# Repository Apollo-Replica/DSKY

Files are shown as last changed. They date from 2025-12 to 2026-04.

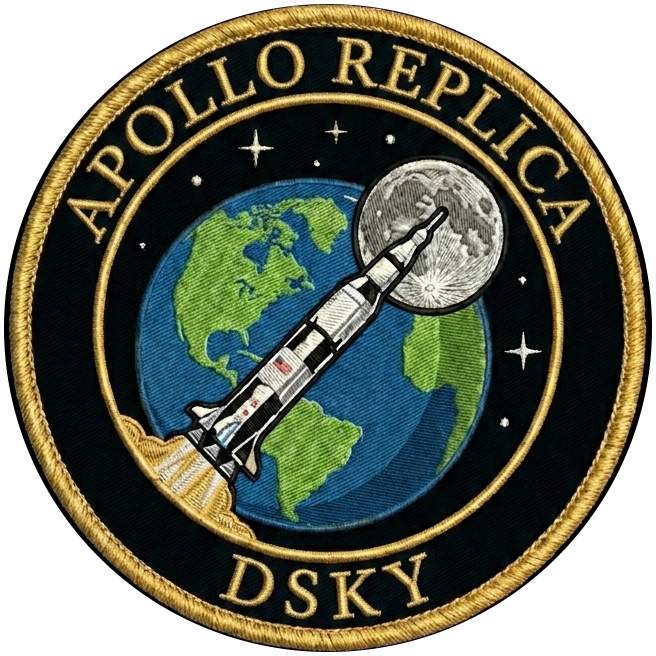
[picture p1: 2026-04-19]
Programs/orangepi-utilities/patch.png

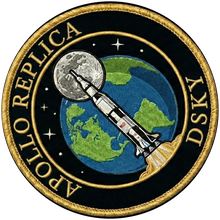
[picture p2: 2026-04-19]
Programs/orangepi-utilities/watermark.png

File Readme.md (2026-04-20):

# DSKY Replica
> This project is still a work-in-progress 

This projects aims to create an affordable and easy to manufacture, yet as realistic as possible replica of the DSKY used in the Apollo program to interface with the Apollo Guidance Computer (AGC).

## Quick start

**Do you want a DSKY but can't build one? Buy one [here](https://shop.ortizma.com)**

**Need Help? Join our Discord [here](https://discord.gg/CHZaYj5UNu)**

**Do you just want to have a DSKY display in your web browser?**
  - Make sure you have NodeJS > 18
  - Run start.bat and answer the prompts

**Do you want to build the whole DSKY replica?**
  - Print the .3mf/.stl meshes found in the '3D Models' folder.
    - The recommended display is the **960x544 AMOLED MIPI display**, connected to the Orange Pi via HDMI through an adapter board.
    - A legacy 40-Pin 5" 800x480 LCD variant also exists but is no longer recommended; new builds should use the AMOLED.
  - Order the PCB:
    - The board is designed to be ordered fully assembled from JLCPCB. The fabrication files (gerbers, BOM, pick-and-place positions) are in the ``Boards/Single_board/production`` folder.
  - Calibrate and flash the firmware:
    - Install PlatformIO into VSCode
    - Open this repository's root folder in VSCode — PlatformIO will pick up ``platformio.ini`` at the root
    - Each ATmega328P has a slightly different internal oscillator. You must first determine your chip's optimal OSCCAL value:
      1. Flash the ``bare_calibration`` environment to run the OSCCAL sweep
      2. Use ``firmware/tools/osccal_reader.py`` to read the sweep results and find the best value
      3. Set the ``-DOSC_CAL=0xNN`` flag in ``platformio.ini`` with your value
      4. Flash the ``bare`` environment with your calibrated firmware
  - Set up the Orange Pi:
    - See the [Orange Pi setup guide](Documentation/orangepi-setup.md).
    - Pre-built .img files have been shared around the community, but they are not recommended as they may be out of date.
  - Make sure you have NodeJS > 18
  - Run start.bat on your PC to launch the web display

## Repository contents:
* **Documentation**: Useful information to better understand how the different pieces of the puzzle talk to each other
* **2D Models**: SVG files for alarm labels and backlights.
* **3D Models**:
  * **0.4 Nozzle:** All printable meshes (enclosure, display housing, keyboard plate, mounts, etc.) designed for a standard 0.4mm nozzle.
  * **Keys (0.2 Nozzle + AMS).3mf:** Multi-color key models for a 0.2mm nozzle with AMS.
* **Firmware:** PlatformIO project containing the firmware for the bare ATmega328P on the PCB. Includes OSCCAL calibration tooling.
* **Programs:**
  * **next-dsky**: Full-stack Next.js application that serves as the main DSKY UI and backend. Handles serial communication with the PCB, WebSocket connections to AGC simulators, display rendering, and configuration.    * Requirements: NodeJS >18
    * Running: ``npm install`` then ``npm start`` (or use ``start.bat`` from the repo root)
  * **DSKY-Bridge**: Submodule ([nhadrian/DSKY-Bridge](https://github.com/nhadrian/DSKY-Bridge)) — bridge utility for the DSKY.
  * **nassp-cloud**: Node.js service that monitors NASSP (orbiter simulator) telemetry via WebSocket and manages automatic restarts.
  * **click-generator**: Python program that procedurally generates relay clicking audio sequences to emulate the DSKY's relay boxes.
* **Boards**
  * **Single_board**: Unified KiCad PCB project containing the keyboard matrix, alarm lights, serial interface, and backlight driver. The ``production`` folder contains ready-to-order JLCPCB fabrication files.

## License

This project is licensed under [Creative Commons Attribution-NonCommercial-ShareAlike 4.0 International (CC BY-NC-SA 4.0)](LICENSE).

You are free to build one for yourself, modify the design, and share your changes — as long as you **credit the original**, **do not use it commercially**, and **release your derivatives under the same license**. Commercial sale of this device or its derivatives is not permitted without prior written consent from the copyright holder.

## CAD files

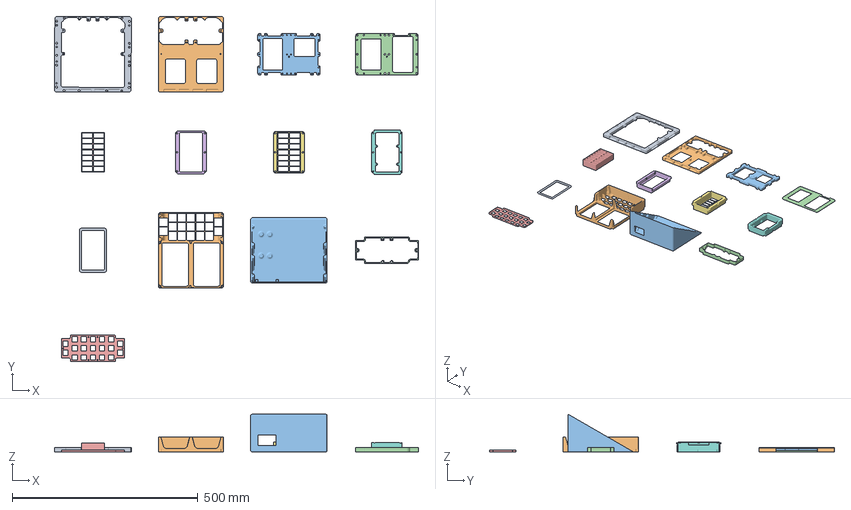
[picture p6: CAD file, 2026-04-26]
3D Models/0.4 Nozzle.3mf
980.6 x 929.7 x 101.6 mm
Mount Bottom
Mount Top
Gasket Bottom
Gasket Top.stl
Alarm Splitter.stl
Alarm Housing Top.stl
Alarm Housing Bottom.stl
Display Housing (OLED).stl
Frame (LCD).stl
Cover (LCD).stl
Compact Enclosure
Keyboard Holder
Keyboard Plate

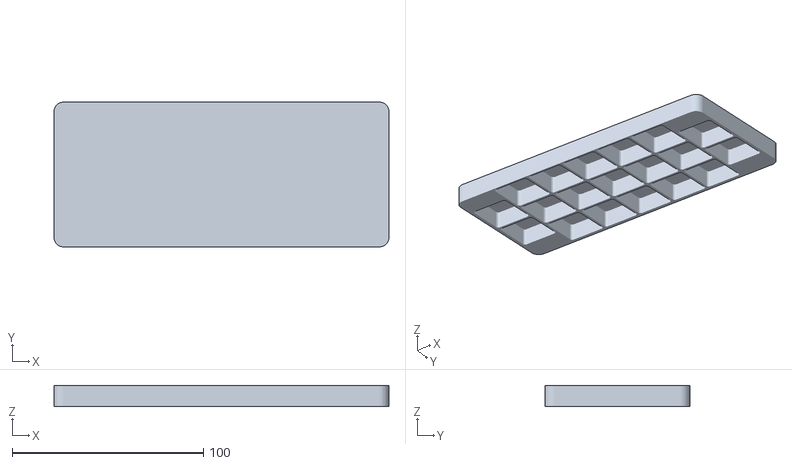
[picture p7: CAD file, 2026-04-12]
3D Models/(TOOL) Key Shipping Holder.stl
175.3 x 75.8 x 11.0

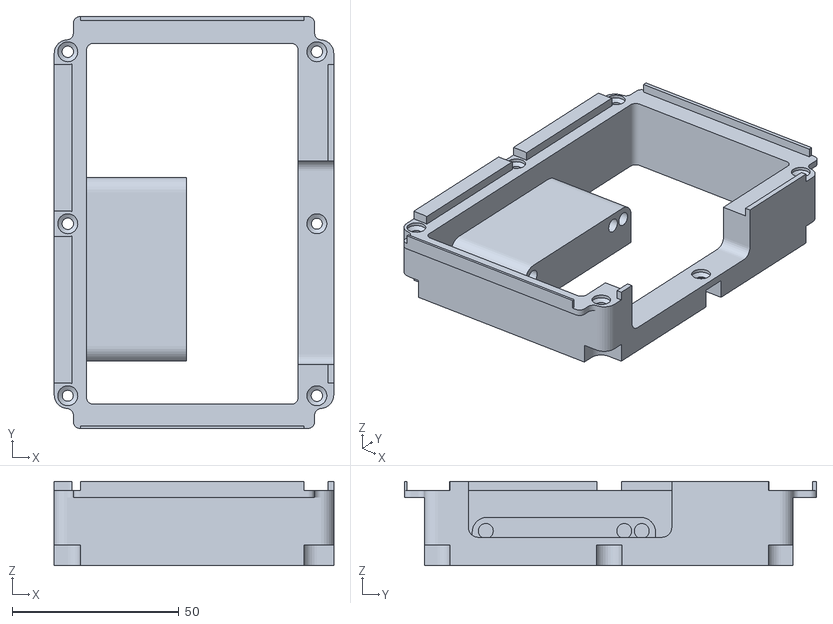
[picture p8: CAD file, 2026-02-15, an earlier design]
3D Models/(OLD) Display Housing (LCD).stl
83.8 x 123.5 x 25.3

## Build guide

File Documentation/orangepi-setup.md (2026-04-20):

# Orange Pi Zero 2W Setup Guide

This guide walks you through setting up an Orange Pi Zero 2W from scratch to run the DSKY software. This is the recommended approach over using pre-built .img files, which may be out of date.

## Base OS

Flash the official **Orange Pi Zero 2W** image (Ubuntu Jammy, arm64) to your SD card using your preferred tool (e.g. balenaEtcher, dd).

Default credentials are typically `orangepi` / `orangepi`.

## Initial setup

After first boot, connect via SSH or a monitor and keyboard.

```bash
# Set hostname
sudo hostnamectl set-hostname dsky

# Update the system
sudo apt update && sudo apt upgrade -y
```

### Create a swap file

The Orange Pi Zero 2W has limited RAM. A swap file helps prevent out-of-memory issues during `npm install` and builds.

```bash
sudo fallocate -l 1G /swapfile
sudo chmod 600 /swapfile
sudo mkswap /swapfile
sudo swapon /swapfile

# Make it permanent
echo '/swapfile swap swap sw 0 0' | sudo tee -a /etc/fstab
```

## Install dependencies

```bash
sudo apt install -y git x11vnc
```

### VirtualAGC (optional)

If you want to run the AGC simulator locally on the Orange Pi:

```bash
sudo apt-get install -y wx2.8-headers libwxgtk2.8-0 libsdl1.2debian libncurses5
```

Build VirtualAGC from source or use a pre-built release. The binaries should end up in `~/VirtualAGC/bin/` (notably `yaAGC`).

## Clone the DSKY repository

```bash
cd ~
git clone https://github.com/Apollo-Replica/DSKY.git
cd DSKY/Programs/next-dsky
npm install
npm run build
```

## Configure appliance-mode boot

Appliance mode boots the Orange Pi straight to the DSKY UI — no desktop, no login prompt, no visible Linux. A helper script does all the setup:

```bash
cd ~/DSKY
bash Programs/orangepi-utilities/setup-appliance-mode.sh
sudo reboot
```

What the script does:

- Installs `openbox`, `feh`, and `unclutter` (minimal WM, splash loader, cursor hider).
- Disables `apt-daily.timer` / `apt-daily-upgrade.timer` and removes `update-manager`/`update-notifier` so auto-updates don't fight the appliance.
- Sets silent kernel boot args in `/boot/orangepiEnv.txt` (`quiet splash loglevel=0`, hides console cursor and blanking).
- Registers a custom `dsky` X session and configures LightDM to auto-login the `orangepi` user into it.
- Creates `~/.xsession`, which launches `openbox` and runs `~/DSKY/orangepi.sh`.
- Silences the `getty@tty1` login banner.
- Swaps the Plymouth boot watermark to the DSKY mission patch.

After reboot: power on → splash image (or black screen) → DSKY UI.

The splash image lives at `~/DSKY/Programs/orangepi-utilities/splash.png`. Use portrait orientation matching your display (e.g. 544×960). If the file is missing the screen stays black until the UI is ready.

## Display rotation

The DSKY display is mounted in portrait orientation, so the HDMI output needs to be rotated 90° counterclockwise. `orangepi.sh` applies an xrandr transform automatically at startup.

The default transform is `0,-1,544,1,0,0,0,0,1`, where `544` is the height of the recommended 960×544 AMOLED display. Override via environment variables in `~/.xsession` (created by the appliance-mode script) only if your display differs:

```bash
#!/bin/bash
export DSKY_XRANDR_OUTPUT=HDMI-1                    # default: HDMI-1
export DSKY_XRANDR_TRANSFORM=0,-1,544,1,0,0,0,0,1   # match your display height
export DSKY_DISPLAY=amoled544                       # or lcd480 for the legacy 800×480 panel
openbox &
~/DSKY/orangepi.sh
```

> For the legacy 800×480 LCD: use `480` in place of `544` in the transform and set `DSKY_DISPLAY=lcd480`. Exporting `DSKY_DISPLAY` in `~/.xsession` is preferred over editing `Programs/next-dsky/.env` — `.xsession` env vars propagate through `orangepi.sh` into `next-dsky` at runtime.

## VNC access (optional)

To remotely view and control the Orange Pi's display:

```bash
# Set a VNC password
x11vnc -storepasswd

# Create a systemd service (more reliable than autostart desktop entries)
sudo tee /etc/systemd/system/x11vnc.service << 'EOF'
[Unit]
Description=x11vnc VNC server
After=display-manager.service

[Service]
Type=simple
ExecStart=/usr/bin/x11vnc -forever -usepw -display :0 -auth guess
User=orangepi
Restart=on-failure
RestartSec=3

[Install]
WantedBy=graphical.target
EOF

sudo systemctl daemon-reload
sudo systemctl enable x11vnc
sudo systemctl start x11vnc
```

## WiFi Connect (optional)

[wifi-connect](https://github.com/balena-os/wifi-connect) provides a captive portal for configuring WiFi on a headless device. The DSKY's configuration UI can trigger it.

```bash
# Install build dependencies
sudo apt install -y build-essential pkg-config libnm-dev libdbus-1-dev network-manager curl

# Install Rust
curl https://sh.rustup.rs -sSf | sh
source "$HOME/.cargo/env"

# Clone and build
git clone https://github.com/balena-os/wifi-connect.git ~/wifi-connect
cd ~/wifi-connect
cargo build --release

# Install the binary
sudo cp target/release/wifi-connect /usr/local/sbin/wifi-connect
```

The `orangepi.sh` launcher script already passes `--wifi-connect` to `next-dsky` when needed.

## Notes

- The Orange Pi connects to the PCB via USB serial (`/dev/ttyUSB0`).
- The `orangepi.sh` script handles display rotation, splash, starting `next-dsky` with the correct serial port, opening Chromium fullscreen, and restarting on crash.
- `unclutter` is launched by `orangepi.sh` to hide the mouse cursor immediately.
- The fstab uses `noatime,commit=600` to reduce SD card writes.
- To revert appliance mode: remove `~/.xsession`, `/etc/lightdm/lightdm.conf.d/50-appliance.conf`, `/usr/share/xsessions/dsky.desktop`, and `/etc/systemd/system/getty@tty1.service.d/override.conf`, then reboot.

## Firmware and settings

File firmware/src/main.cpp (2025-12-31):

#include <Arduino.h>
#include "alarms.h"
#include "keyboard.h"
#include "osc_calibration.h"

using namespace std;

const uint8_t PACKET_SIZE = 16;
constexpr uint32_t SERIAL_BAUD = 9600;
uint8_t dskyState[PACKET_SIZE];
uint8_t memoryLocation = 0;
uint8_t verbPresses = 0; // RGB Mode
uint8_t lightMode = 0;

void setup() {
#if defined(OSC_CAL_SWEEP)
  runOscCalibrationSweep();
  while (true) {}
#endif

  // Initialize state as only the RESTART alarm at low brightness.
  // This improves the chances that the OrangePi will boot successfully
  // while indicating correct Atmega power up.
  for(uint8_t i = 0; i<PACKET_SIZE;i++) dskyState[i] = 0x00;
  dskyState[12] = 0x04;
  dskyState[14] = 20;

  applyOscCalFromBuildFlag();
  Serial.begin(SERIAL_BAUD);
  initAlarms();
}

bool proPressed = false;
void loop() {
  // Serial input
  if(Serial.available() > 0){
    uint8_t receivedByte = Serial.read(); // Read the incoming byte

    if (receivedByte == 0xFF) { // Check if received byte is 0xFF
      memoryLocation = 0; // Reset the array index
    } else {
      dskyState[memoryLocation] = receivedByte; // Store the byte in the array
      memoryLocation = (memoryLocation + 1) % PACKET_SIZE; // Increment array index and wrap around if necessary
    }
  }

  // Keyboard input
  char pressedKey = getKey();
  if(pressedKey){
    Serial.println(pressedKey);
    if(pressedKey == 'P') proPressed = true;
    if(pressedKey != 'V') verbPresses = 0;
    if(pressedKey == 'V') verbPresses++;
  }
  if(getState() == RELEASED && proPressed){
    proPressed = false;
    Serial.println("O");
  }

  // Lighting
  if(verbPresses == 3){
    lightMode = (lightMode + 1) % 3;
    verbPresses = 0;
  }
  if(pressedKey == '+' && lightMode != 0){
    dskyState[14] = min(dskyState[14] + 20, 127);
    dskyState[15] = dskyState[14];
  }
  if(pressedKey == '-' && lightMode != 0){
    dskyState[14] = max(dskyState[14] - 20, 0);
    dskyState[15] = dskyState[14];
  }

  if (lightMode == 0) {
    // Display dsky state using neopixels
    updateAlarms(dskyState);
  }else if(lightMode == 1){
    // Display colorwheel effect
    colorWheel(dskyState);
  }else if(lightMode == 2){
    // Display colorwheel effect
    christmasEffect();
  }
}

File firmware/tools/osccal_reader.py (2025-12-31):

#!/usr/bin/env python3
"""
OSCCAL sweep reader for the calibration firmware.

The firmware emits bursts shaped like:
  0xA5 <cal_byte> 64 * 0x55 0x5A

This script listens on a serial port, parses bursts, scores them by how many
0x55 bytes were received correctly, and prints the best OSCCAL observed.

Usage:
  python osccal_reader.py --port COM3 --baud 115200 --bursts 40

Notes:
- Install dependency: pip install pyserial
- Match baud to the calibration firmware (default 115200).
- If your firmware uses a different burst length or markers, adjust constants
  below or override with CLI flags.
"""
from __future__ import annotations

import argparse
import collections
import sys
import time
from typing import Dict, List, Optional, Tuple

try:
    import serial  # type: ignore
    from serial.tools import list_ports  # type: ignore
except ImportError:
    print("pyserial is required. Install with: pip install pyserial", file=sys.stderr)
    sys.exit(1)


DEFAULT_BURST_LEN = 64
HEADER = 0xA5
FOOTER = 0x5A
PATTERN_BYTE = 0x55


Frame = Tuple[int, bytes]
Score = Tuple[int, int]  # (total correct, longest run)


def longest_run_of(byte_val: int, data: bytes) -> int:
    best = cur = 0
    for b in data:
        if b == byte_val:
            cur += 1
            if cur > best:
                best = cur
        else:
            cur = 0
    return best


def score_payload(payload: bytes) -> Score:
    correct = sum(1 for b in payload if b == PATTERN_BYTE)
    run = longest_run_of(PATTERN_BYTE, payload)
    return correct, run


def extract_frames(buf: bytearray, burst_len: int) -> Tuple[List[Frame], bytearray]:
    frames: List[Frame] = []
    i = 0
    min_frame = 2 + burst_len + 1  # header + cal + payload + footer
    while i <= len(buf) - min_frame:
        if buf[i] != HEADER:
            i += 1
            continue

        if i + min_frame > len(buf):
            break  # not enough data yet

        cal = buf[i + 1]
        payload = bytes(buf[i + 2 : i + 2 + burst_len])
        footer = buf[i + 2 + burst_len]
        if footer == FOOTER:
            frames.append((cal, payload))
            i += min_frame
        else:
            # Bad footer; discard this header and continue scanning
            i += 1

    # Trim processed bytes
    return frames, buf[i:]


def pick_best(scores: Dict[int, List[Score]]) -> Tuple[int, Score]:
    best_cal = None
    best_score: Score = (-1, -1)
    for cal, cal_scores in scores.items():
        cal_best = max(cal_scores)
        if cal_best > best_score:
            best_score = cal_best
            best_cal = cal
    if best_cal is None:
        raise RuntimeError("No valid frames decoded.")
    return best_cal, best_score


def summarize(scores: Dict[int, List[Score]], burst_len: int) -> Dict[int, Dict[str, float]]:
    summary: Dict[int, Dict[str, float]] = {}
    for cal, cal_scores in scores.items():
        corrects = [s[0] for s in cal_scores]
        runs = [s[1] for s in cal_scores]
        frames = len(cal_scores)
        summary[cal] = {
            "frames": frames,
            "avg_correct": sum(corrects) / frames,
            "min_correct": min(corrects),
            "max_correct": max(corrects),
            "avg_run": sum(runs) / frames,
            "max_run": max(runs),
            "perfect_frames": sum(1 for c in corrects if c == burst_len),
        }
    return summary


def best_perfect_span(scores: Dict[int, List[Score]], burst_len: int) -> Optional[Tuple[int, int, int]]:
    # Find the longest contiguous span of CAL values that had at least one perfect frame.
    perfect_cals = sorted(cal for cal, cal_scores in scores.items() if any(s[0] == burst_len for s in cal_scores))
    if not perfect_cals:
        return None
    best_span = (perfect_cals[0], perfect_cals[0])
    cur_start = cur_end = perfect_cals[0]
    for cal in perfect_cals[1:]:
        if cal == cur_end + 1:
            cur_end = cal
        else:
            if (cur_end - cur_start) > (best_span[1] - best_span[0]):
                best_span = (cur_start, cur_end)
            cur_start = cur_end = cal
    if (cur_end - cur_start) > (best_span[1] - best_span[0]):
        best_span = (cur_start, cur_end)
    mid = (best_span[0] + best_span[1]) // 2
    return best_span[0], best_span[1], mid


def auto_detect_port(preferred: Optional[str] = None) -> str:
    if preferred and preferred.lower() != "auto":
        return preferred

    ports = list(list_ports.comports())
    if not ports:
        raise RuntimeError("No serial ports found. Specify --port explicitly.")

    # Heuristic: prefer CH340/USB-Serial/USBasp-like descriptors.
    def weight(p) -> int:
        desc = (p.description or "").lower()
        hwid = (p.hwid or "").lower()
        score = 0
        if "ch340" in desc or "ch341" in desc:
            score += 4
        if "usb" in desc:
            score += 2
        if "usb" in hwid:
            score += 1
        return score

    ports.sort(key=weight, reverse=True)

    chosen = ports[0]
    print("Auto-selected port:", chosen.device)
    if len(ports) > 1:
        print("Other candidates:")
        for p in ports[1:]:
            print(f"  {p.device}: {p.description}")
    return chosen.device
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

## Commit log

2025-12-28 Developed resin keys with no paint required
    [+ Shell.stl, - Shell.stl, 0 Shell.stl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]
2025-12-28 printable backlights
    [sketch.dxf]
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2026-01-02 Add backlights SVG and PDF files; remove outdated sketch DXF file
    [sketch.dxf]
2026-01-18 Refactor integration architecture by introducing AgcIntegration base class and ConfigIntegration for configuration management. Remove legacy configState.ts and integrate its functionality into the ne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
2026-01-18 Implement manual URL input feature in configuration flow. Update ConfigDisplay and ConfigPageContent components to handle new step and text input. Enhance ConfigIntegration to manage text input and v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
2026-01-19 Enhance configuration flow by adding network interface selection for Windows. Update ConfigIntegration to handle multiple network interfaces and adjust step logic accordingly. Modify server initializ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
2026-01-19 Refactor serial handling and configuration completion in ConfigIntegration. Update `closeSerial` and `performReset` to use async/await for better error handling and ensure proper closure of serial co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
2026-01-20 Add WiFi configuration option to next-dsky. Update orangepi.sh to support --wifi-connect argument, enhance ConfigIntegration to handle WiFi setup, and modify UI components to allow WiFi configuration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
2026-01-21 fix brightness clamping issue
2026-02-15 Simplify models structure & add new OLED holder by @nhadrian
    [+ Shell.stl, +.stl, - Shell.stl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]
2026-02-16 Update Keyboard Plate model based on @nhadrian 's model
    [Keyboard Plate.stl, Keyboard Plate_33Leds.stl, Keyboard Plate_34Leds.stl]
2026-04-11 Add Home Assistant mini-AGC core
    Implement the internal AGC state machine for the HA integration:
    - types/config.ts: Shared TypeScript interfaces for config state
    - nounAssignment.ts: Sequential noun ID assignment utility
    - types.ts: AGC state, noun config, verb handler interfaces
    - nouns.ts: Noun registry with built-in clock (N36/N65) and HA entity mapping
    - verbs.ts: V06 (display), V16 (monitor), V21-V25 (load registers),
    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
2026-04-11 Add Home Assistant WebSocket connection and entity discovery
    - haConnection.ts: WebSocket connection to HA using home-assistant-js-websocket,
    real-time entity state subscription, service calls, and 10s connection timeout
    - entityDiscovery.ts: Discover available HA entities, filter system entities,
    generate noun mappings per domain, and persist to ha_entities.json
    - settings.ts: Load config from env vars, wizard options, or persisted
    ha_entities.json with auto-start detection for reboot persistence
    - Add home-assistant-js-websocket dependency
2026-04-11 Add Home Assistant config wizard steps
    - config.ts: Add haSetup/haUrl/haToken/haDiscover/haEntities steps,
    entity discovery, toggle all/individual selection, URL/token persistence.
    Use shared ConfigState/ConfigResult types from types/config.ts
    - index.ts: Handle config:done and config:toggle messages, pass HA options
    to integration, auto-start from persisted ha_entities.json on reboot
    - mdnsService.ts: Use shared DiscoveredAPI type
    Config flow: source → haSetup (shows DSKY URL for phone access) →
    haUrl → haToken → haDiscover → haEntities → confirm
2026-04-11 Add config UI for Home Assistant steps
    - ConfigDisplay.tsx: Render haSetup (DSKY URL for phone config),
    haUrl/haToken text inputs, haDiscover loading/error, haEntities
    multi-select with toggle all, confirm summary with device assignments.
    Use shared ConfigState type
    - ConfigPageContent.tsx: Skip keyboard handling for text input steps,
    add config:done and config:toggle actions. Use shared ConfigState type
2026-04-11 Add help panel sidebar and housekeeping
    - helpPanel.tsx: Slide-in sidebar showing device noun assignments,
    available commands, and keyboard reference. Only visible in HA mode
    - help.css: Sidebar styling with smooth slide transition
    - homeContent.tsx: Pass config state to help panel
    - globals.css: Import help.css
    - .gitignore: Exclude ha_entities.json, keep .env.example
    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
2026-04-12 Update README and remove iPhone display variants
    Drop iPhone 12 Mini and iPhone 13 3D models and all references.
    Update README to reflect current project state: unified single board
    with JLCPCB assembly, OSCCAL calibration workflow, AMOLED MIPI display
    as recommended option, next-dsky as the unified app, and updated
    repository contents.
    [Compact Mount (iPhone 12 Mini).3mf, Compact Mount (iPhone 13).3mf, Cover (iPhone 12 Mini).3mf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]
2026-04-12 Reorganize 3D/2D models and add Orange Pi setup guide
    - Consolidate 3D models into "0.4 Nozzle" folder and AMS key file,
    removing old Common, LCD-OLED, Keys (SLA), Keys (SLA+Paint)(OLD),
    and Keys (FDM) folders.
    - Move 2D files (SVGs) to top-level "2D Models" folder.
    - Add Orange Pi Zero 2W setup guide in Documentation.
    - Update README to reflect new folder structure.
    [(TOOL) Key Shipping Holder.stl, + Shell.stl, +.stl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]
2026-04-12 Update 3D models: remove unused parts, replace Compact Enclosure with .3mf
    [Alarm Pipe (Optional).stl, Alarm Splitter (With Light Pipes).stl, Compact Enclosure.3mf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]
2026-04-13 Add alarm labels SVG and adjust mask fill color
    Add a separate alarms_labels.svg for the overlay mode where labels render
    above the chassis image. Tweak the mask fill from #747474 to #585c64 to
    better match the physical DSKY panel tone.
2026-04-13 Add DSKY chassis PNG for full-skin view mode
    Used as the background image in the new overlay/full view mode where
    display, alarms, and keyboard are positioned over the photo.
2026-04-13 Remove help panel sidebar in favor of menu system
    The help panel (floating ? button + slide-out sidebar) is replaced by the
    new DSKY menu overlay which provides the same commands reference plus
    device navigation and settings.
2026-04-13 Refactor alarms component for overlay and screen render modes
    Replace CSS-class-based alarm indicators with data-driven rendering using
    alarm definition arrays. Support two modes:
    - overlay: absolute-positioned color rectangles behind the DSKY chassis
    image with a separate labels SVG on top
    - screen: color bands behind the SVG mask for standalone screen view
    Use DskyState type for props instead of any.
2026-04-13 Add config step navigation API for menu-driven setup
    Add gotoStep() and selectSourceDirect() to ConfigIntegration so the menu
    UI can jump directly to any config step or auto-confirm simple sources.
    Wire four new WebSocket message types in the server:
    - config:goto, config:select-source for in-config navigation
    - config:reset-and-goto, config:reset-and-select-source for atomic
    reset + jump (avoids client-side race conditions)
2026-04-13 Integrate menu overlay and dual view modes into homeContent
    Replace the old keyboard toggle + help panel with the new menu system:
    - Add full (DSKY chassis photo) and screen-only view modes
    - Wire DSKY key events through the menu navigation hook before relaying
    to the server, so physical keys can navigate the menu
    - Auto-open menu when server sends config 'source' step (replaces the
    old router.push('/config') redirect)
    - Improve type safety: replace any casts with AudioContext, AudioBuffer,
    ConfigState, and proper timer types
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2026-04-13 Retune alarm positions and colors for updated chassis image
    Adjust overlay and screen-mode alarm coordinates to match the new
    DSKY PNG. Switch alarm palette from blue/yellow to warm white/orange.
2026-04-13 Make menu overlay background transparent
    Lets the DSKY chassis show through behind the menu content area.
2026-04-13 Remove unused legacy keyboard component and styles
    Replaced by DskyKeyboard with transparent overlay buttons.
2026-04-13 Add calculator screen with expression display and key hints
    Registers its own key handler via appKeyHandlerRef to intercept
    DSKY keys directly. Shows expression history, current result,
    and a grid of key mappings.
2026-04-13 Add clock screen with tabbed stopwatch/countdown/alarm/pomodoro modes
    +/- keys switch between tabs. Each tab delegates key handling to
    its respective hook or component. Registers via appKeyHandlerRef
    for direct DSKY key input.
2026-04-13 Add app key handler with triple-N back navigation
    Apps register their own key handler via appKeyHandlerRef to intercept
    DSKY keys directly. Pressing N three times in a row navigates back
    to the menu from any app screen. Also wires apps item count into
    the screen navigation system.
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2026-04-13 Fix indentation of selectedIndex prop in screen-mode overlay
2026-04-15 Replace ConfigState type with ServerState for flat server-broadcast model
    The old ConfigState tracked wizard step/flow state. ServerState models
    the actual server state (app, serial, network, bridge, HA, wifi) and is
    broadcast to all clients, decoupling the UI from server-side wizards.
2026-04-15 Remove legacy config wizard, config page, and server ConfigIntegration
    Configuration is now handled by in-menu screens that send action
    messages directly, so the multi-step wizard flow and its server-side
    state machine are no longer needed.
2026-04-15 Refactor server to broadcast ServerState with action-based messages
    Replace the config wizard state machine with a flat ServerState object
    and action:* message handlers. Add networkInterfaces utility for
    multi-NIC detection. The server now responds to discrete actions
    (switch-app, set-serial, list-ports, etc.) instead of wizard steps.
2026-04-15 Add in-menu screens for yaAGC, bridge, serial, network, wifi, and HA
    Nine new screens replace the old config wizard flow:
    - yaagcVersion, bridgeSelect: simulation source pickers
    - serialSelect, networkInterface, wifi: hardware settings
    - haUrl, haToken, haDiscover, haEntities: Home Assistant setup wizard
    Also adds sourceConstants and new MenuScreen type entries.
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2026-04-17 streamline 3d models
    [(OLD) Display Housing (LCD).stl, (TOOL) Key Shipping Holder.stl, 0.4 Nozzle.3mf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]
2026-04-17 update slicer settings
    [0.4 Nozzle.3mf]
2026-04-17 Redesign simulator icons and add bridge manual-URL screen
    Replace generic glyphs with custom SVG icons that evoke each simulator
    (rocket for SIMS, binary code for yaAGC, gears for NASSP, angled capsule
    with trailing plasma for Reentry, planet with dashed orbit for KSP).
    Rename the main-menu "SIMULATE" item to "SIMS".
    The bridge menu's MANUAL URL option now opens a dedicated screen with a
    text input and Connect button instead of closing the menu, letting the
    user type a wss:// URL from the web UI. The global key relay skips
    INPUT/TEXTAREA targets so typing no longer steers the DSKY menu.
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2026-04-19 Unify OLED_MODE and DISPLAY_TYPE into a single DSKY_DISPLAY variant
    Replaces OLED_MODE and DISPLAY_TYPE with DSKY_DISPLAY (amoled544 default,
    lcd480 for the legacy 800x480 LCD). The variant drives both the chassis
    background color and the display-<variant> CSS hook, so a single env var
    (or ?display= query param) now captures the whole display profile.
    Adds an AMOLED/LCD switch next to FULL/SCR and SOUND/MUTE in ViewToggle
    for live preview, and drops the unused display-iphone12/13 CSS rules.
2026-04-19 Keep 800x480 transform note simple and mention DSKY_DISPLAY
    Revert the tuned-matrix suggestion back to the minimal 544→480 swap
    (that customization is per-device and shouldn't be baked into the
    guide), and add a reminder to also set DSKY_DISPLAY=lcd480 in
    next-dsky's .env so the UI variant matches the physical panel.
2026-04-19 Switch boot logo from u-boot BMP to Plymouth watermark
    The Orange Pi 5 boot logo is drawn by Plymouth (theme "orangepi"),
    not u-boot — /boot/boot.bmp isn't referenced by boot.cmd. Replace the
    unused BMP output with a transparent watermark.png sized for Plymouth
    and wire the setup-appliance-mode.sh script to install it and rebuild
    the initramfs. The watermark is pre-rotated 90° CCW so it reads
    upright on the physically-portrait panel (Plymouth draws at native
    landscape; xrandr only rotates after X starts).
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2026-04-19 Fold appliance-specific service tweaks into the setup script
    - setup-appliance-mode.sh now disables apt-daily timers and removes
    update-manager / update-notifier alongside the package install, so
    a fresh Ubuntu image needs only the script (plus git clone) to
    reach an appliance-ready state.
    - Drop the matching "Disable unnecessary services" block from the doc.
    - Drop xttitle and wmctrl from the documented apt install — both are
    unused (wmctrl is only referenced in orangepi.sh's cron branch,
    left intact but no longer installed by default).
    - Document that DSKY_DISPLAY can be exported from ~/.xsession instead
    of edited into next-dsky/.env (it propagates at runtime), which is
    mor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
2026-04-20 Swap Gorton font for Share Tech Mono and drop reference repos
    Replace the bundled Gorton OTF with Share Tech Mono loaded via
    next/font/google so the font is self-hosted at build time under a
    permissive OFL license. Update clock, calculator, and toggle-label
    font stacks to the new CSS variable with a monospace fallback chain.
    Drop the "Repositories used as reference" section from the README.
2026-04-20 Fix stale DSKY repo URL in Orange Pi setup guide
    The clone URL pointed at the old Apollo-Simulation-Peripheral-Lab org
    instead of the current Apollo-Replica one.
2026-04-20 Restore NASSP verb/noun flash after === refactor
    The refactor that tightened loose equality to strict broke blanking:
    NASSP emits flashing as the string "1"/"0", so flashing === 1 was
    always false and the UI never saw the blanked half of the cycle.
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2026-04-26 add missing parts
    [0.4 Nozzle.3mf]
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2026-10-27 Flash over USB with urboot, keep OSCCAL in EEPROM
    The single board has a CH340C with DTR auto-reset but no bootloader, and
    "Burn bootloader" with a Nano selected sets crystal fuses on a board with
    no crystal. env:bare_usb_bootloader burns MiniCore's urboot (autobaud) with
    internal 8 MHz fuses E2/D7/FD once through the USBasp; env:bare_usb then
    uploads over the board's USB-C at 38400.
    OSCCAL moves from a per-board -DOSC_CAL build to EEPROM byte 0, so every
    board runs the same firmware (-DOSC_CAL still overrides). The sweep now
    runs at 38400: 115200 is 3.5 % off at 8 MHz and calibrated the clock 3.5 %
    fast, which put the app's 9600 link out by as much. osccal_reader.py reads
    the whole sweep,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
2026-10-27 Add DSKY Flasher: bootloader and firmware setup per board
    A tkinter tool in the style of the IoT Manager, packaged by build.bat into
    a portable folder with avrdude and the hex images. The Bootloader tab
    burns urboot and fuses on each board put on the USBasp, skipping boards
    that already have them. The Firmware tab handles every board plugged in
    over USB-C: calibrates OSCCAL into EEPROM when missing, uploads the
    firmware unless it already matches, and checks OSCCAL survived.
    A USBasp without a driver gets WinUSB from driver/wdi-simple.exe, libwdi
    built as a command line tool and patched for Windows 8+ (inbox WinUSB, no
    WDK coinstallers); build-wdi-simple.sh rebuilds it from the patch.
    Co-Au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
2026-10-28 DSKY Flasher: key test after flashing
    Each board that finishes in the Firmware tab stays connected at 9600 and
    counts the key presses the firmware prints, until it's unplugged. A line
    that isn't a key (or the PRO release) is a glitch. The result goes to
    flash_log.csv as a keytest row.
    build.bat runs PlatformIO through python -m, since pio isn't always on PATH.
    Claude-Session: https://claude.ai/code/session_011U2v9eebVjVkU4Kvm2BRCq
